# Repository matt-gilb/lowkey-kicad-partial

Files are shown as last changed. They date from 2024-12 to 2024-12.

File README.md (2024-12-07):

# LowKey36 by Matt Gilbert

This is the ZMK source repo for the LowKey36 spit keyboard.

## This is a prototype!

This repo holds the basic KiCAD files I used to create the prototype of the LowKey36 (v1.2), but it doesn't have all the component symbols/footprints included. As a result you will probably get errors trying to open/edit the PCB design.

Once I have the public-ready v2.0 procduced, I will remove this repo to avoid confusion. For now I'm sharing it for those who are curious.

You can find the ZMK files for the LowKey36 [here](https://github.com/matt-gilb/zmk-config-lowkey36.git).

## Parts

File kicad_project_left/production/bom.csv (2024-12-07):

Designator | Footprint | Quantity | Value | LCSC Part #
D1, D10, D11, D12, D13, D14, D15, D16, D17, D18, D2, D3, D4, D5, D6, D7, D8, D9 | D_SOD-123 | 18 | D
DISPLAY1 | nice_view | 1 | nice!view
JBATT1, JGND1 | SolderWirePad_1x01_SMD_1x2mm | 2 | Conn_01x01
PWR1 | SW_SSSS811101 | 1 | MSK12C02
RST1 | Panasonic_EVQPUJ_EVQPUA | 1 | SW_Push
SW1, SW10, SW11, SW12, SW13, SW14, SW15, SW16, SW2, SW3, SW4, SW5, SW6, SW7, SW8, SW9 | CPG1316S01D02 | 16 | SW_Push
SW17, SW18 | CPG1316S-1.5w | 2 | SW_Push
U1 | nice_nano | 1 | Nice_Nano_V2

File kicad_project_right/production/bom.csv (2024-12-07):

Designator | Footprint | Quantity | Value | LCSC Part #
D19, D20, D21, D22, D23, D24, D25, D26, D27, D28, D29, D30, D31, D32, D33, D34, D35, D36 | D_SOD-123 | 18 | D
DISPLAY2 | nice_view | 1 | nice!view
JBATT2, JGND2 | SolderWirePad_1x01_SMD_1x2mm | 2 | Conn_01x01
PWR2 | SW_SSSS811101 | 1 | MSK12C02
RST2 | Panasonic_EVQPUJ_EVQPUA | 1 | SW_Push
SW19, SW20, SW21, SW22, SW23, SW24, SW25, SW26, SW27, SW28, SW29, SW30, SW31, SW32, SW33, SW34 | CPG1316S01D02 | 16 | SW_Push
SW35, SW36 | CPG1316S-1.5w | 2 | SW_Push
U2 | nice_nano | 1 | Nice_Nano_V2

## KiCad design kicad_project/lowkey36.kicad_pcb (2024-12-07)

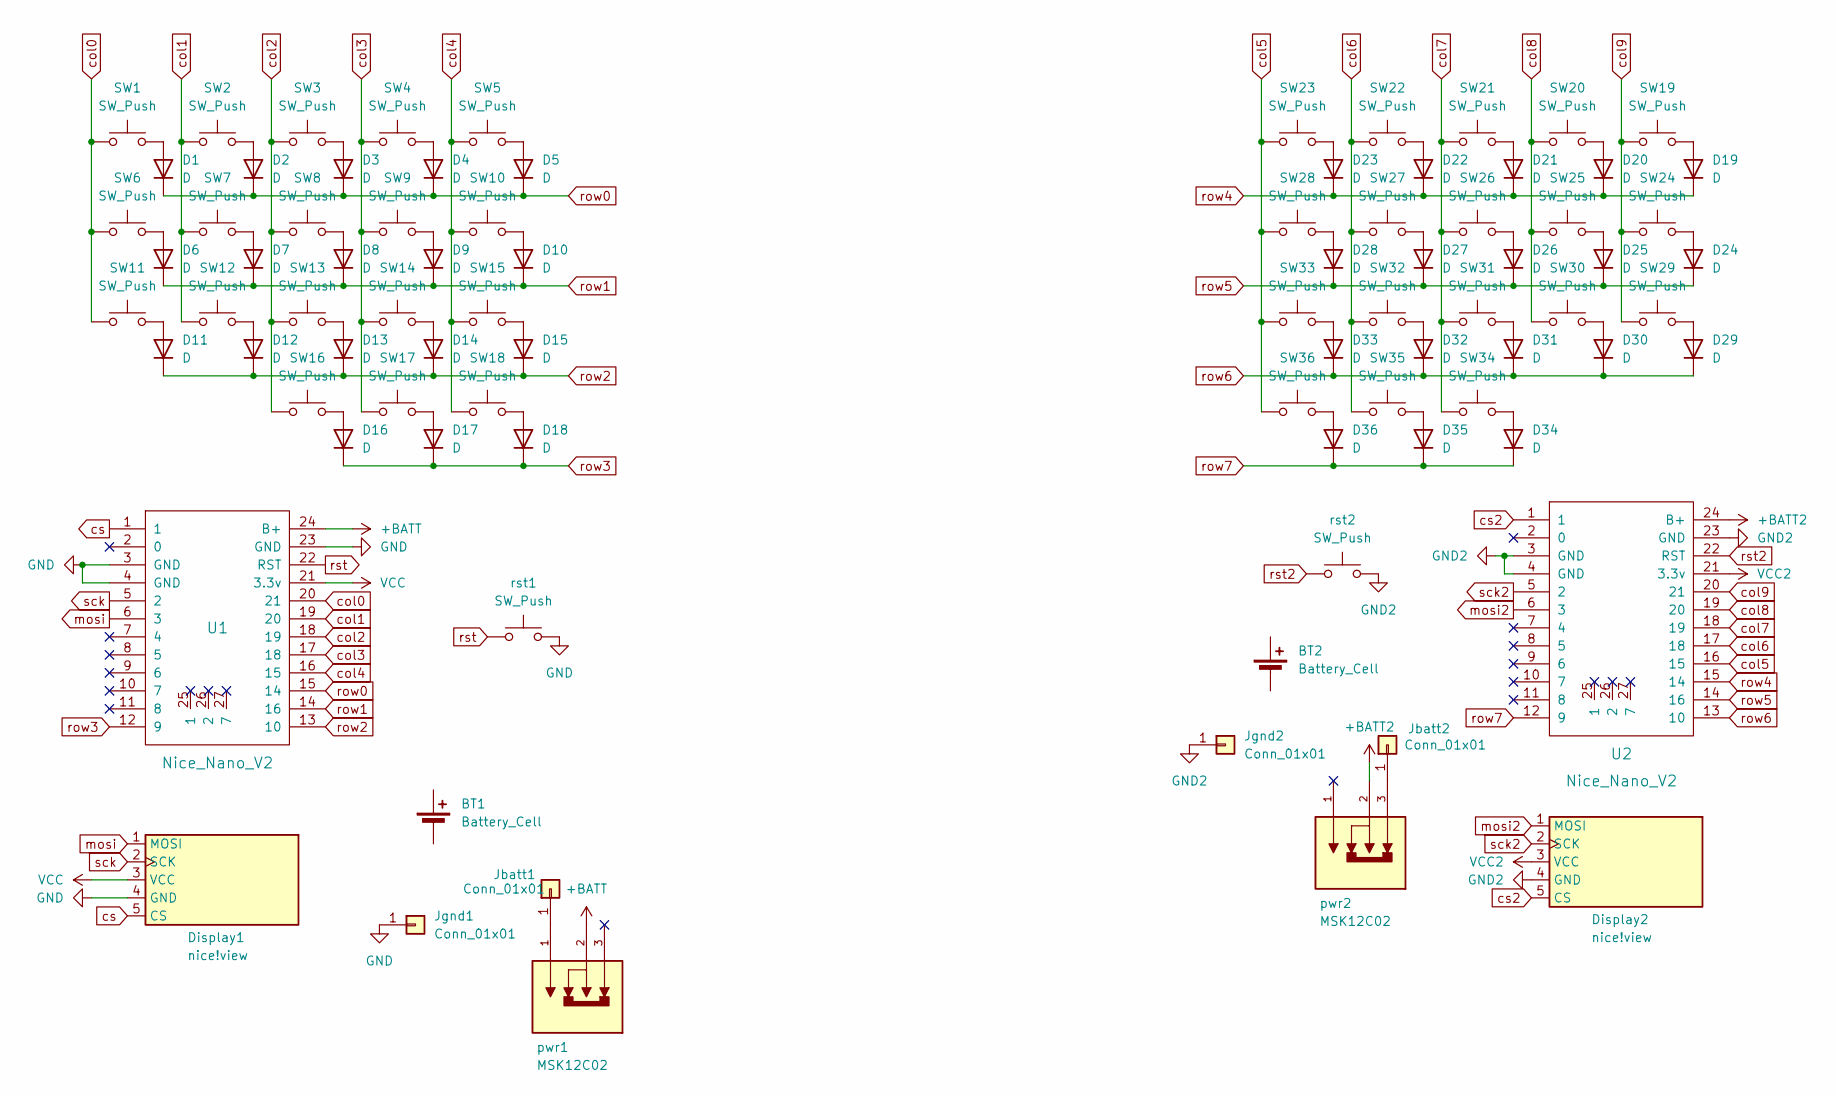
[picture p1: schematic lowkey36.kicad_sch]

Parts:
BT1, BT2: Battery_Cell
D1, D2, D3, D4, D5, D6, D7, D8, D9, D10, D11, D12, D13, D14, D15, D16, D17, D18, D19, D20, D21, D22, D23, D24, D25, D26, D27, D28, D29, D30, D31, D32, D33, D34, D35, D36: D; D_SOD-123
Display1, Display2: nice!view; nice_view
Jbatt1, Jbatt2: Conn_01x01; SolderWirePad_1x01_SMD_1x2mm
Jgnd1, Jgnd2: Conn_01x01; SolderWirePad_1x01_SMD_1x2mm
SW1, SW2, SW3, SW4, SW5, SW6, SW7, SW8, SW9, SW10, SW11, SW12, SW13, SW14, SW15, SW16, SW19, SW20, SW21, SW22, SW23, SW24, SW25, SW26, SW27, SW28, SW29, SW30, SW31, SW32, SW33, SW34: SW_Push; CPG1316S01D02
SW17, SW18, SW35, SW36: SW_Push; CPG1316S-1.5w
U1: Nice_Nano_V2
U2: Nice_Nano_V2; nice_nano
pwr1, pwr2: MSK12C02; SW_SSSS811101; PARTREV N/A
rst1, rst2: SW_Push; Panasonic_EVQPUJ_EVQPUA

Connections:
+BATT: U1.24 (B+), pwr1.2
+BATT2: U2.24 (B+), pwr2.2
GND: Display1.4 (GND), Jgnd1.1, U1.3 (GND), U1.4 (GND), U1.23 (GND), rst1.2
GND2: Display2.4 (GND), Jgnd2.1, U2.3 (GND), U2.4 (GND), U2.23 (GND), rst2.2
unnamed: D1.2 (A), SW1.2
unnamed: D2.2 (A), SW2.2
unnamed: D3.2 (A), SW3.2
unnamed: D4.2 (A), SW4.2
unnamed: D5.2 (A), SW5.2
unnamed: D6.2 (A), SW6.2
unnamed: D7.2 (A), SW7.2
unnamed: D8.2 (A), SW8.2
unnamed: D9.2 (A), SW9.2
unnamed: D10.2 (A), SW10.2
unnamed: D11.2 (A), SW11.2
unnamed: D12.2 (A), SW12.2
unnamed: D13.2 (A), SW13.2
unnamed: D14.2 (A), SW14.2
unnamed: D15.2 (A), SW15.2
unnamed: D16.2 (A), SW16.2
unnamed: D17.2 (A), SW17.2
unnamed: D18.2 (A), SW18.2
unnamed: D19.2 (A), SW19.2
unnamed: D20.2 (A), SW20.2
unnamed: D21.2 (A), SW21.2
unnamed: D22.2 (A), SW22.2
unnamed: D23.2 (A), SW23.2
unnamed: D24.2 (A), SW24.2
unnamed: D25.2 (A), SW25.2
unnamed: D26.2 (A), SW26.2
unnamed: D27.2 (A), SW27.2
unnamed: D28.2 (A), SW28.2
unnamed: D29.2 (A), SW29.2
unnamed: D30.2 (A), SW30.2
unnamed: D31.2 (A), SW31.2
unnamed: D32.2 (A), SW32.2
unnamed: D33.2 (A), SW33.2
unnamed: D34.2 (A), SW34.2
unnamed: D35.2 (A), SW35.2
unnamed: D36.2 (A), SW36.2
unnamed: Jbatt1.1, pwr1.1
unnamed: Jbatt2.1, pwr2.3
VCC: Display1.3 (VCC), U1.21 (3.3v)
VCC2: Display2.3 (VCC), U2.21 (3.3v)
col0: SW1.1, SW6.1, SW11.1, U1.20 (21)
col1: SW2.1, SW7.1, SW12.1, U1.19 (20)
col2: SW3.1, SW8.1, SW13.1, SW16.1, U1.18 (19)
col3: SW4.1, SW9.1, SW14.1, SW17.1, U1.17 (18)
col4: SW5.1, SW10.1, SW15.1, SW18.1, U1.16 (15)
col5: SW23.1, SW28.1, SW33.1, SW36.1, U2.16 (15)
col6: SW22.1, SW27.1, SW32.1, SW35.1, U2.17 (18)
col7: SW21.1, SW26.1, SW31.1, SW34.1, U2.18 (19)
col8: SW20.1, SW25.1, SW30.1, U2.19 (20)
col9: SW19.1, SW24.1, SW29.1, U2.20 (21)
cs: Display1.5 (CS), U1.1
cs2: Display2.5 (CS), U2.1
mosi: Display1.1 (MOSI), U1.6 (3)
mosi2: Display2.1 (MOSI), U2.6 (3)
row0: D1.1 (K), D2.1 (K), D3.1 (K), D4.1 (K), D5.1 (K), U1.15 (14)
row1: D6.1 (K), D7.1 (K), D8.1 (K), D9.1 (K), D10.1 (K), U1.14 (16)
row2: D11.1 (K), D12.1 (K), D13.1 (K), D14.1 (K), D15.1 (K), U1.13 (10)
row3: D16.1 (K), D17.1 (K), D18.1 (K), U1.12 (9)
row4: D19.1 (K), D20.1 (K), D21.1 (K), D22.1 (K), D23.1 (K), U2.15 (14)
row5: D24.1 (K), D25.1 (K), D26.1 (K), D27.1 (K), D28.1 (K), U2.14 (16)
row6: D29.1 (K), D30.1 (K), D31.1 (K), D32.1 (K), D33.1 (K), U2.13 (10)
row7: D34.1 (K), D35.1 (K), D36.1 (K), U2.12 (9)
rst: U1.22 (RST), rst1.1
rst2: U2.22 (RST), rst2.1
sck: Display1.2 (SCK), U1.5 (2)
sck2: Display2.2 (SCK), U2.5 (2)

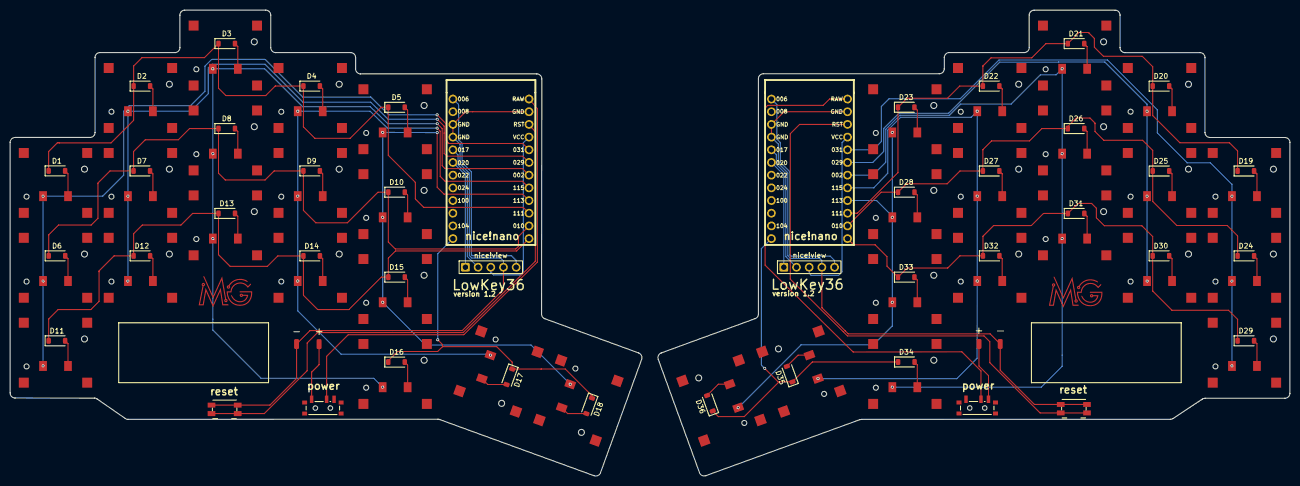
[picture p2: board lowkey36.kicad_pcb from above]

Board: 2 copper layers, 256.2 x 93.3 mm, 84 parts (0 on the bottom side), 70 nets.
